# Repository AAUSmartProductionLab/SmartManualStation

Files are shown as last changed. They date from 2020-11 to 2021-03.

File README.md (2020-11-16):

 # Smart Manual Station overview
 The Smart Manual Station is a project developed at Aalborg University as a smart digital aid for the worker at a manual station. The station consists of:

  * Table on wheels 
  * Raspberry pi as the "brain"
  * Pick By Light setup
  * OPC-UA server
  * Simple GUI

further future features includes:
  * mqtt support
  * Storage database of pick by light setup
  * Implementation of RFID-scanner
  * Webinterface
  
 # The station itself

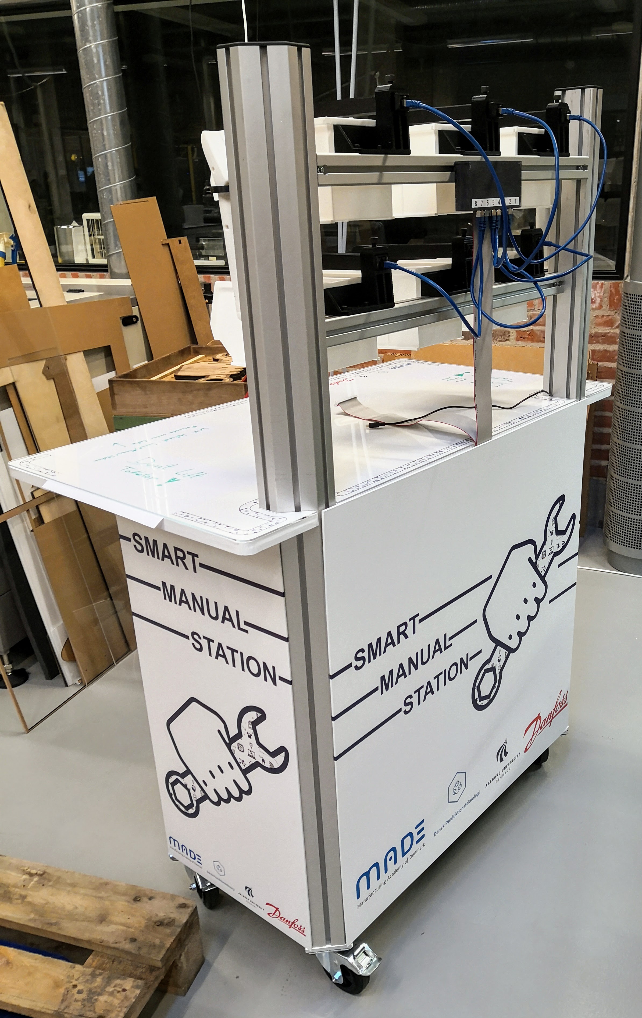
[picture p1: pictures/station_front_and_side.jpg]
  
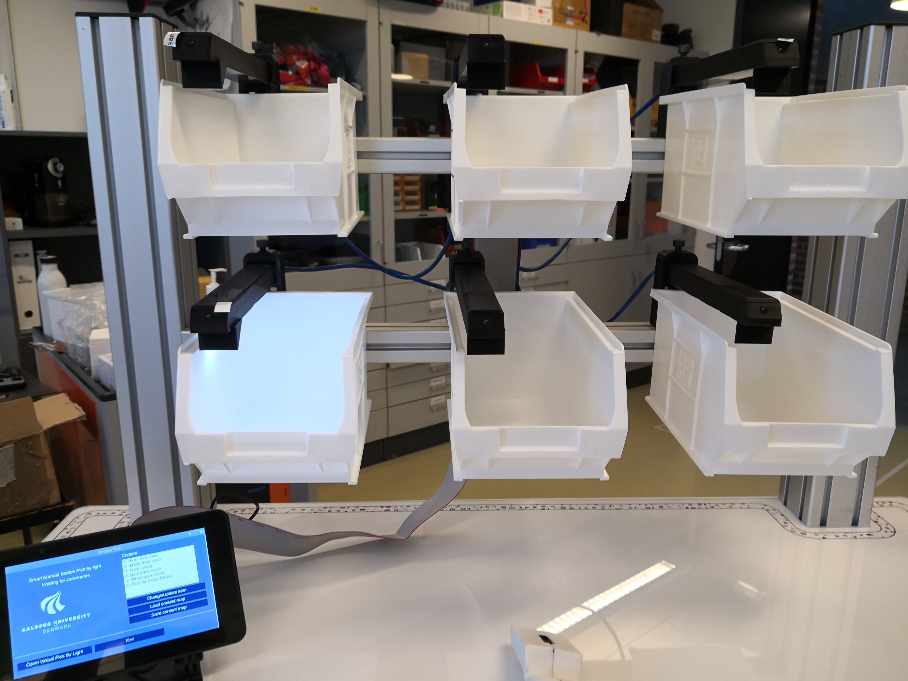
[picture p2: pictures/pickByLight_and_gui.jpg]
  

 # Graphical Unser Interface 
The graphical userinterface is build with [PySimpleGui](https://pysimplegui.readthedocs.io/en/latest/)  
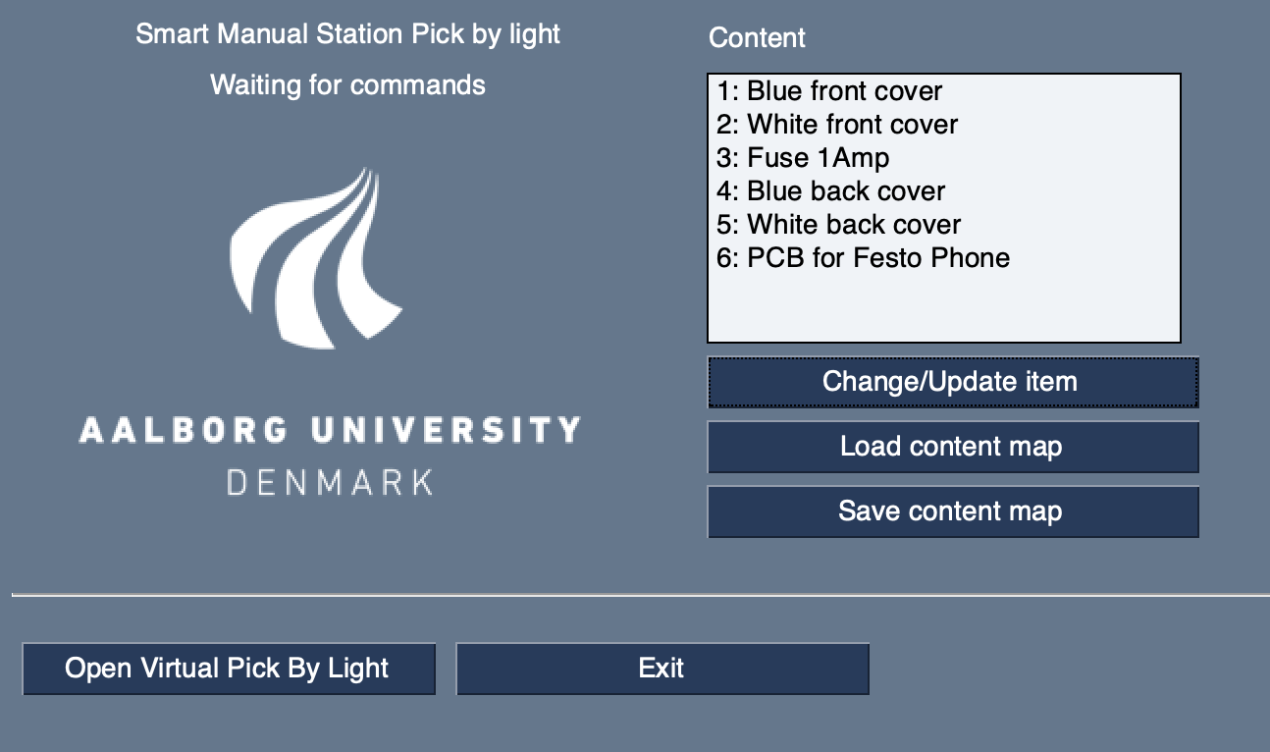
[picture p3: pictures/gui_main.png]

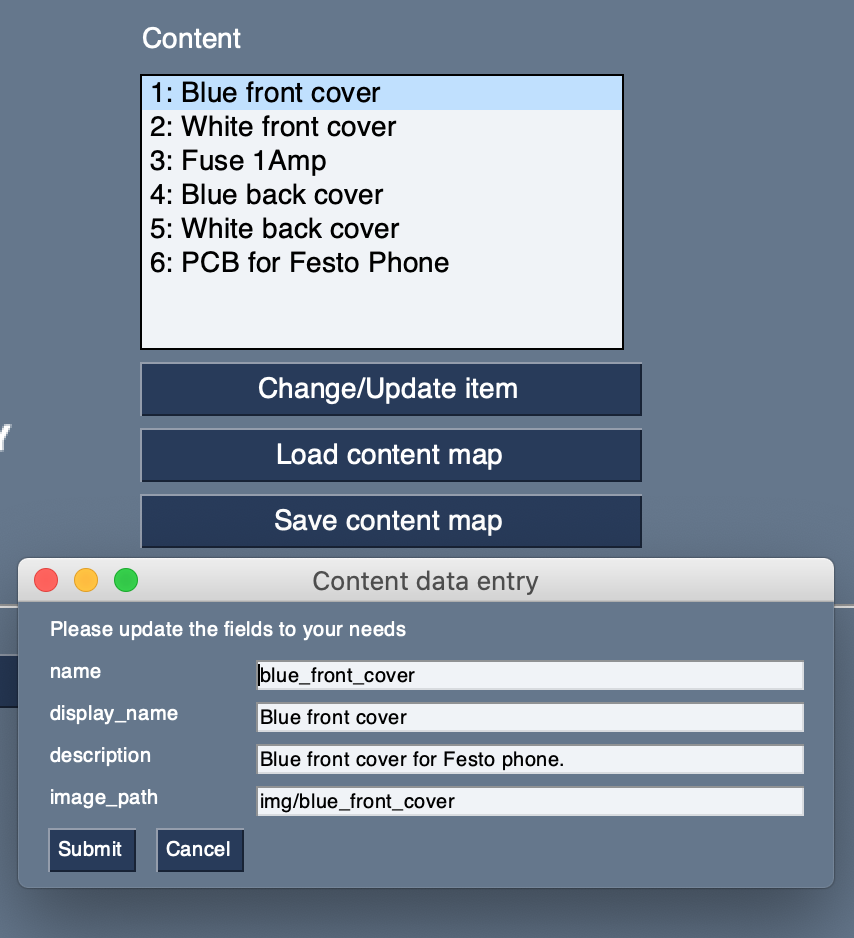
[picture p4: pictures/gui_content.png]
  

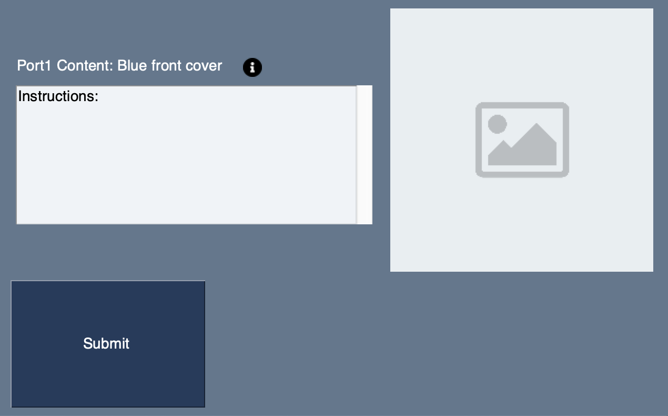
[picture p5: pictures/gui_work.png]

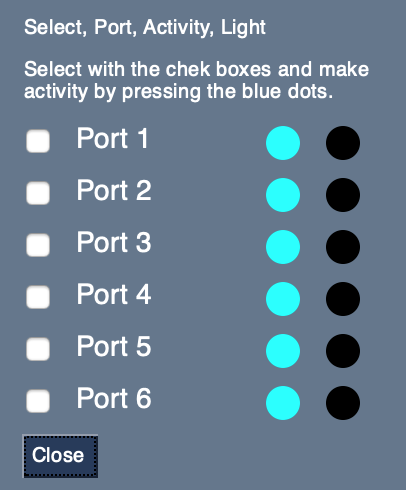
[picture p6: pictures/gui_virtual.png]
  

 # PCB breakout box
Added as a git subtree to this repository. Dedicated upstream repo can be found [here](https://github.com/hjalte33/rpi-pcb)  

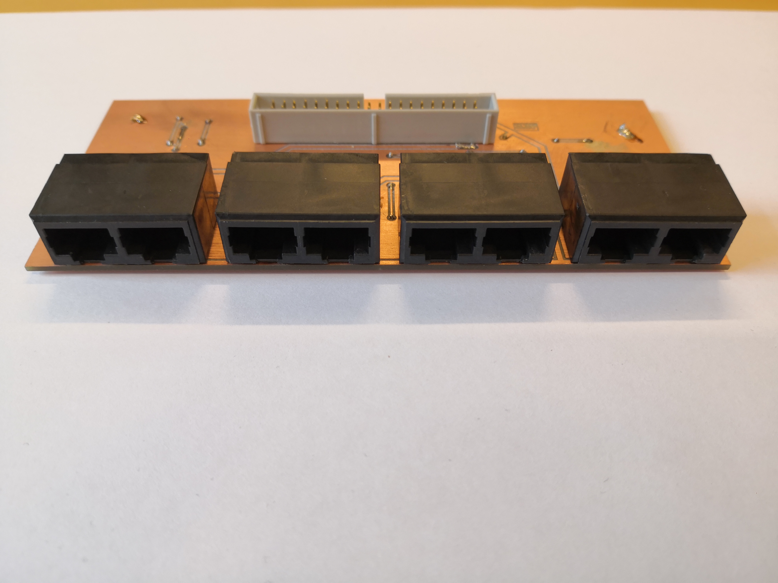
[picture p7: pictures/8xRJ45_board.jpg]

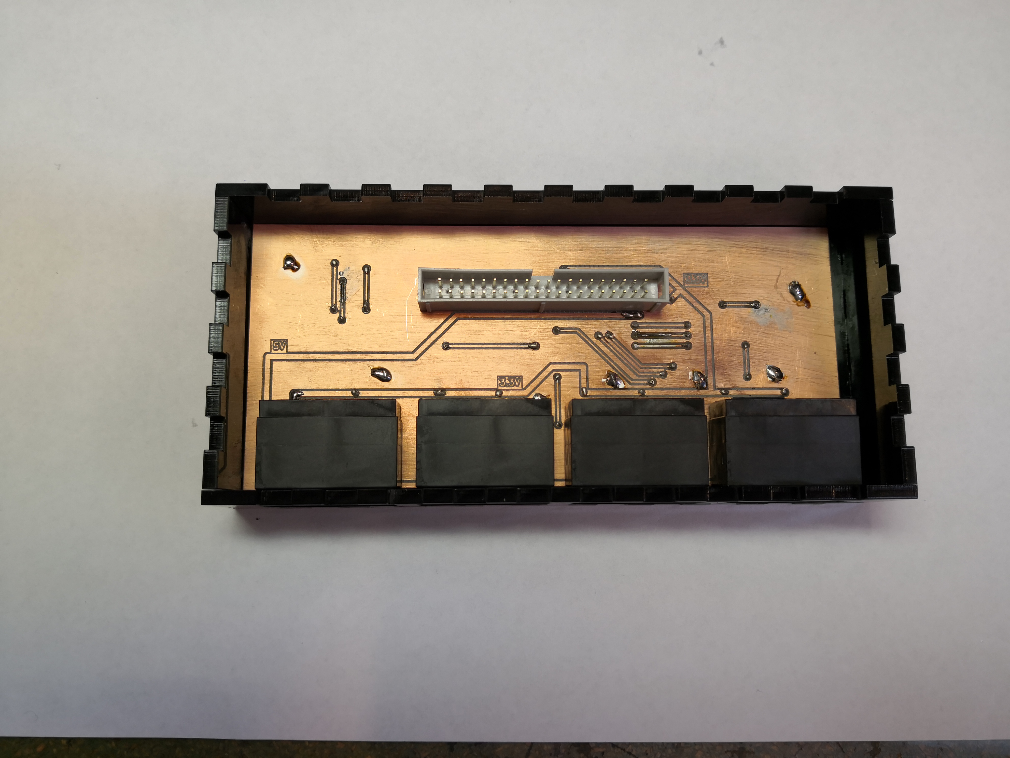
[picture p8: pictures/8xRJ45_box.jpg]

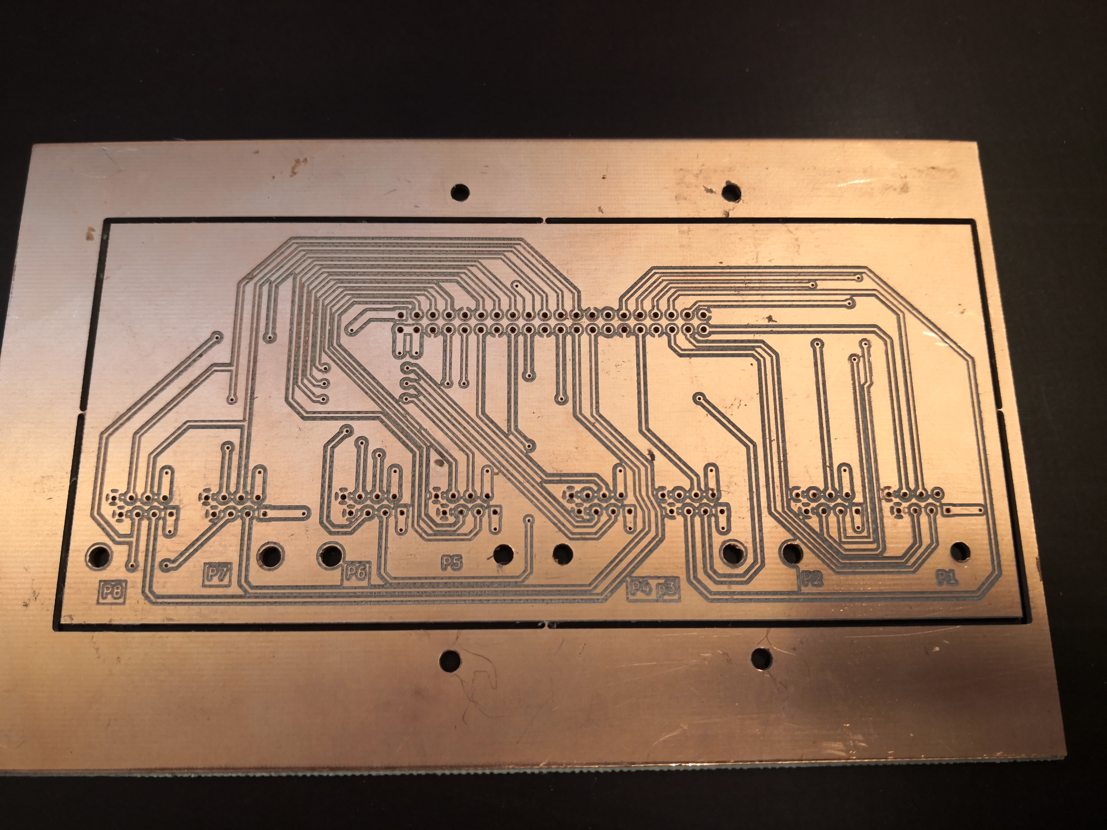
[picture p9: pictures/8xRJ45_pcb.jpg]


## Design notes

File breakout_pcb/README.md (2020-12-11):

# rpi-pcb is a Breakout board for raspberry pi.
With this breakout board you get eight rj45 ports with both 5v and 3.3v and three GPIOs in each port (exept port 8).
The various features of the the pins have been distributed nicely in a way that I think makes sense so for instance: 
 * Hardware SPI pins are all an port 1
 * Hardware I2C pins on port 5
 * Port 2, 3 and 4 each have a hardware pwm and gpclk pin
 * Port 6 have the UART tx and rx pins 
 * Port 7 and 8 have a shared SPI interface each with their own chip select pin.

See The full pinout [in the included pdf documentation](8xRJ45%20breakout%20board%20for%20raspberry%20pi%20-%20pinout.pdf)

    

## Box  
The repository also includes a nice lasercut box that fits snugly around the pcb.  


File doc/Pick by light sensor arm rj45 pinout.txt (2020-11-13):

1:5V
2:3.3V
3:PIR
4:LED
5:NC
6:NC
7:gnd
8:gnd

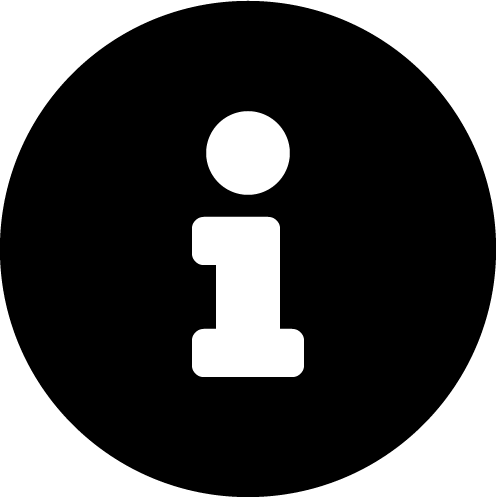
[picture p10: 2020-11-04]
src/img/info-circle-solid.png

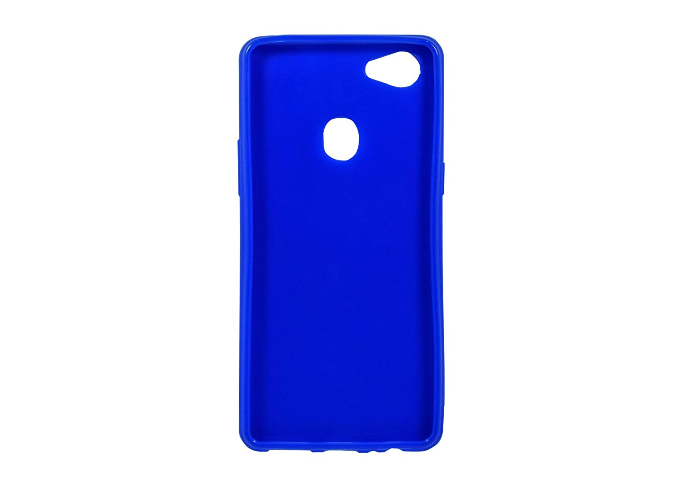
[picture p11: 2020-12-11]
src/img/blue_front_cover.jpg

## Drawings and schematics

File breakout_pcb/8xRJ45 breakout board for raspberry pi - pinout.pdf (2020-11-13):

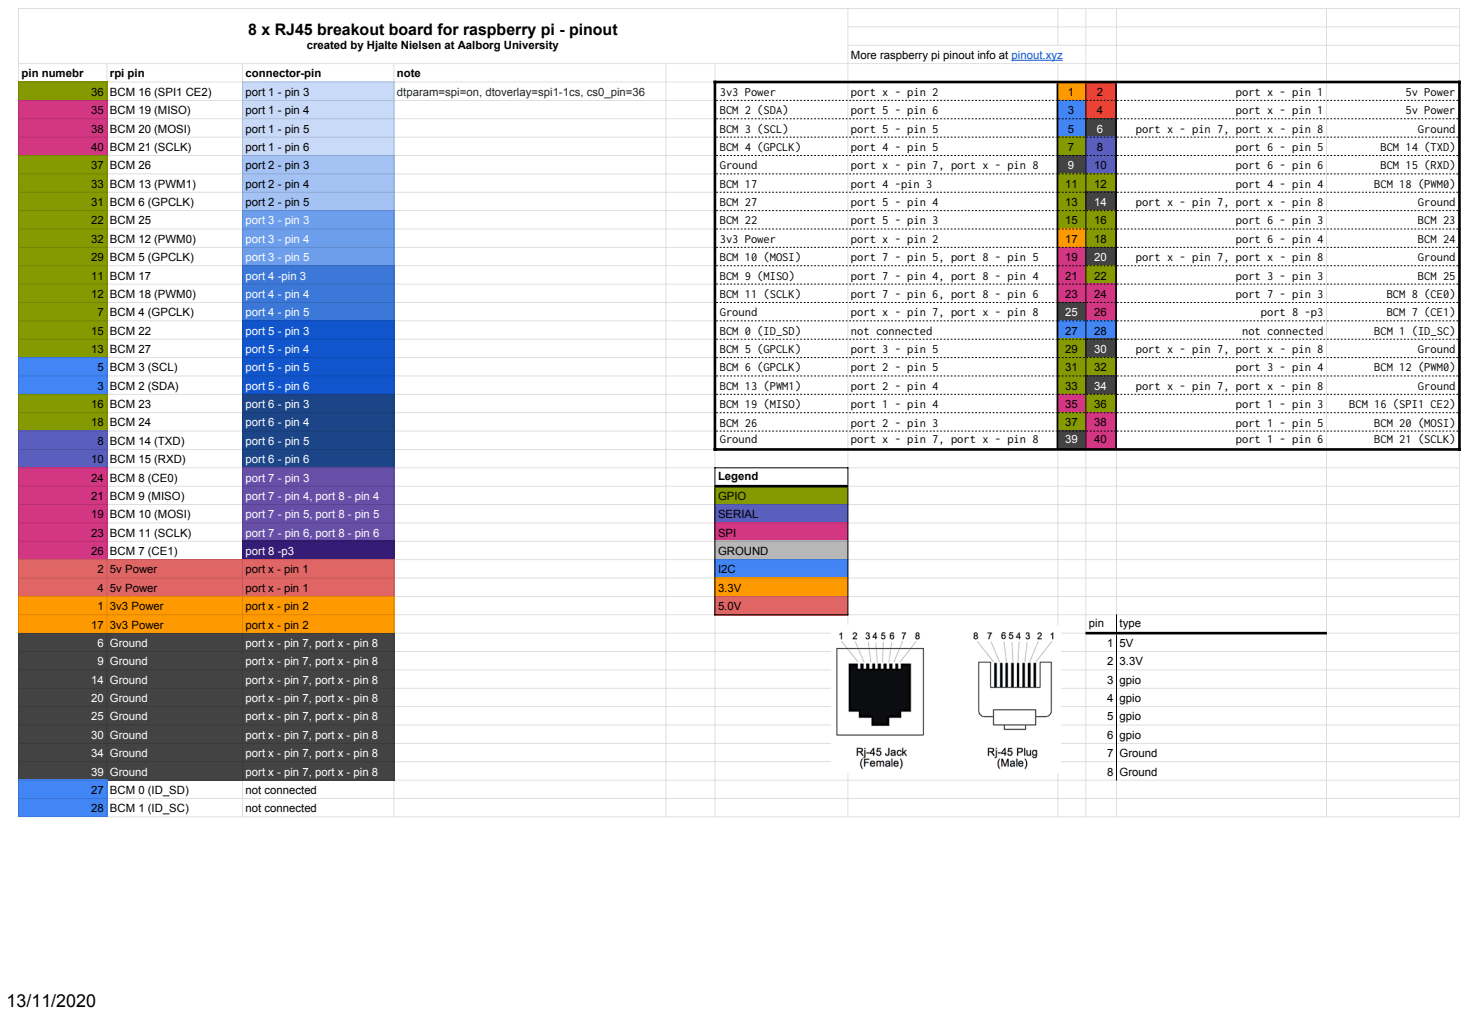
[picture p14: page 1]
created by Hjalte Nielsen at Aalborg University; More raspberry pi pinout info at pinout.xyz; pin numebr; rpi pin; connector-pin; note; 36 BCM 16 (SPI1 CE2); port 1 - pin 3; dtparam=spi=on, dtoverlay=spi1-1cs, cs0_pin=36; 3v3 Power; port x - pin 2; port x - pin 1; 5v Power; 35 BCM 19 (MISO); port 1 - pin 4; BCM 2 (SDA); port 5 - pin 6; 38 BCM 20 (MOSI); port 1 - pin 5; BCM 3 (SCL); port 5 - pin 5; port x - pin 7, port x - pin 8; Ground; 40 BCM 21 (SCLK); port 1 - pin 6; BCM 4 (GPCLK)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

8 x RJ45 breakout board for raspberry pi - pinout

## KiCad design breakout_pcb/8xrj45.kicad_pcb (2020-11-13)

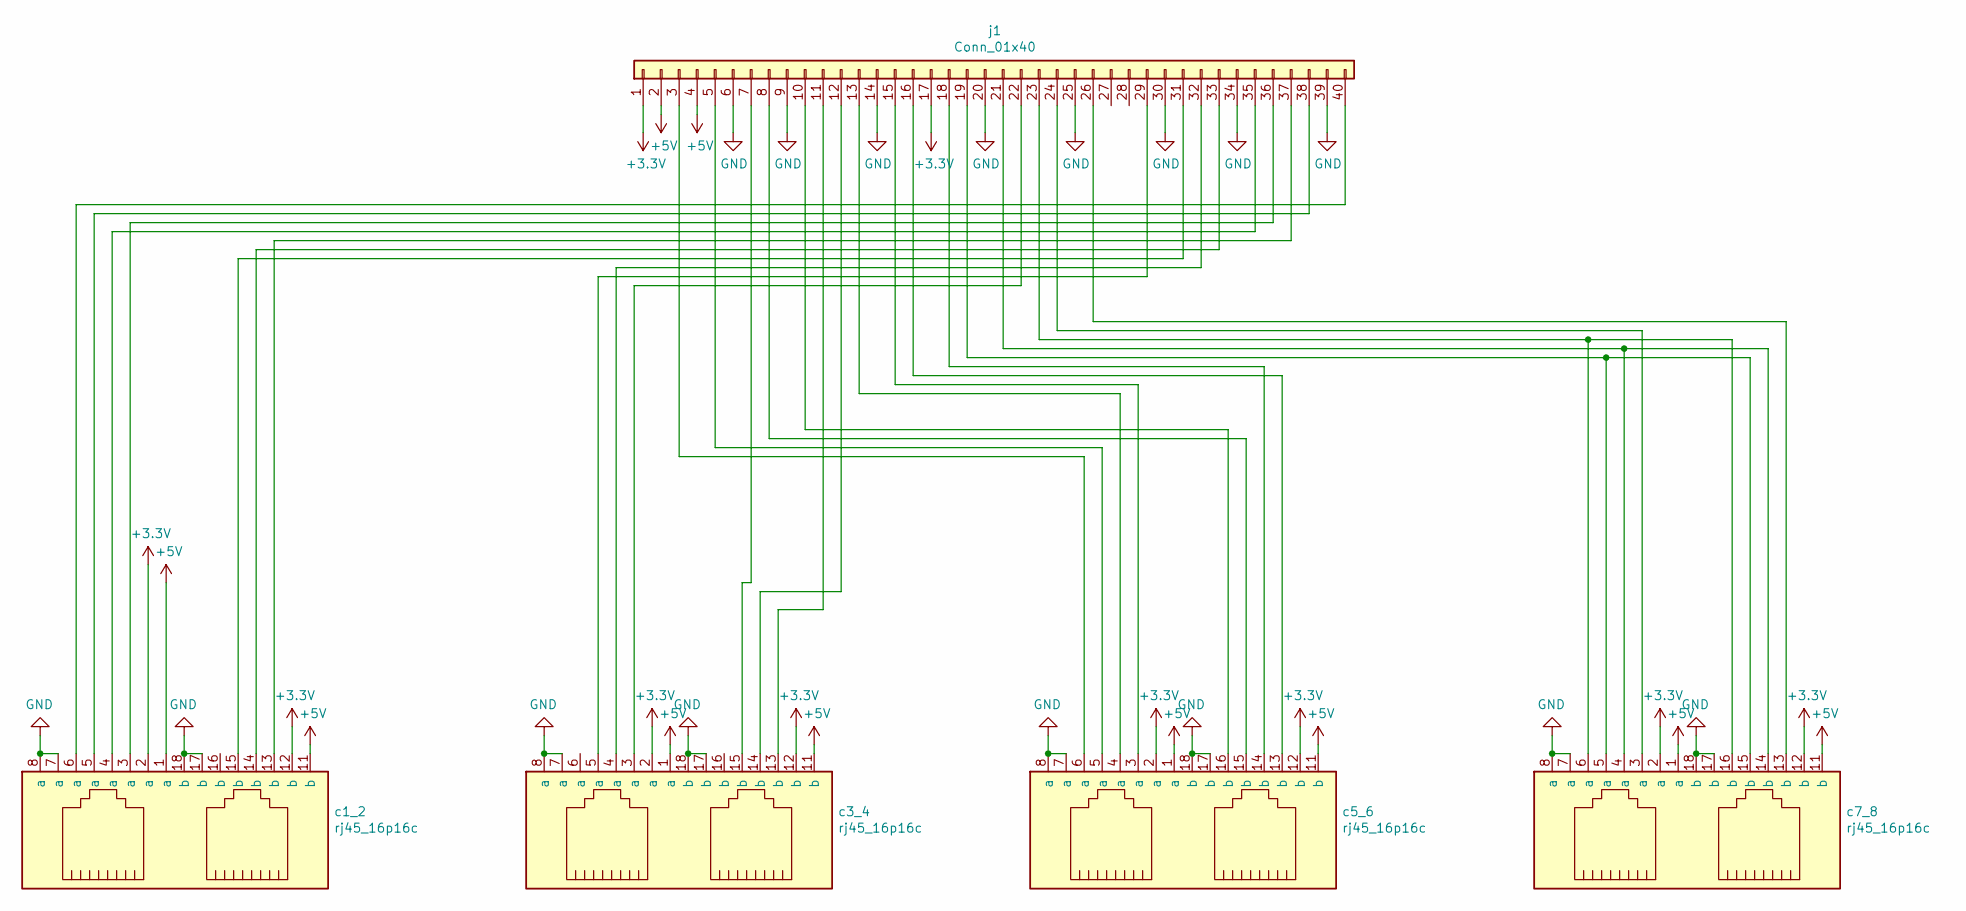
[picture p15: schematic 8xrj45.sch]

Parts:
c1_2, c3_4, c5_6, c7_8: rj45_16p16c; 2xrj45_connector
j1: Conn_01x40; IDC-Header_2x20_P2.54mm_Vertical

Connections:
+3V3: c1_2.2 (a), c1_2.12 (b), c3_4.2 (a), c3_4.12 (b), c5_6.2 (a), c5_6.12 (b), c7_8.2 (a), c7_8.12 (b), j1.1, j1.17
+5V: c1_2.1 (a), c1_2.11 (b), c3_4.1 (a), c3_4.11 (b), c5_6.1 (a), c5_6.11 (b), c7_8.1 (a), c7_8.11 (b), j1.2, j1.4
GND: c1_2.7 (a), c1_2.8 (a), c1_2.17 (b), c1_2.18 (b), c3_4.7 (a), c3_4.8 (a), c3_4.17 (b), c3_4.18 (b), c5_6.7 (a), c5_6.8 (a), c5_6.17 (b), c5_6.18 (b), c7_8.7 (a), c7_8.8 (a), c7_8.17 (b), c7_8.18 (b), j1.6, j1.9, j1.14, j1.20, j1.25, j1.30, j1.34, j1.39
unnamed: c1_2.3 (a), j1.36
unnamed: c1_2.4 (a), j1.35
unnamed: c1_2.5 (a), j1.38
unnamed: c1_2.6 (a), j1.40
unnamed: c1_2.13 (b), j1.37
unnamed: c1_2.14 (b), j1.33
unnamed: c1_2.15 (b), j1.31
unnamed: c3_4.3 (a), j1.22
unnamed: c3_4.4 (a), j1.32
unnamed: c3_4.5 (a), j1.29
unnamed: c3_4.13 (b), j1.11
unnamed: c3_4.14 (b), j1.12
unnamed: c3_4.15 (b), j1.7
unnamed: c5_6.3 (a), j1.15
unnamed: c5_6.4 (a), j1.13
unnamed: c5_6.5 (a), j1.5
unnamed: c5_6.6 (a), j1.3
unnamed: c5_6.13 (b), j1.16
unnamed: c5_6.14 (b), j1.18
unnamed: c5_6.15 (b), j1.8
unnamed: c5_6.16 (b), j1.10
unnamed: c7_8.3 (a), j1.24
unnamed: c7_8.13 (b), j1.26
unnamed: c7_8.4 (a), c7_8.14 (b), j1.21
unnamed: c7_8.5 (a), c7_8.15 (b), j1.19
unnamed: c7_8.6 (a), c7_8.16 (b), j1.23

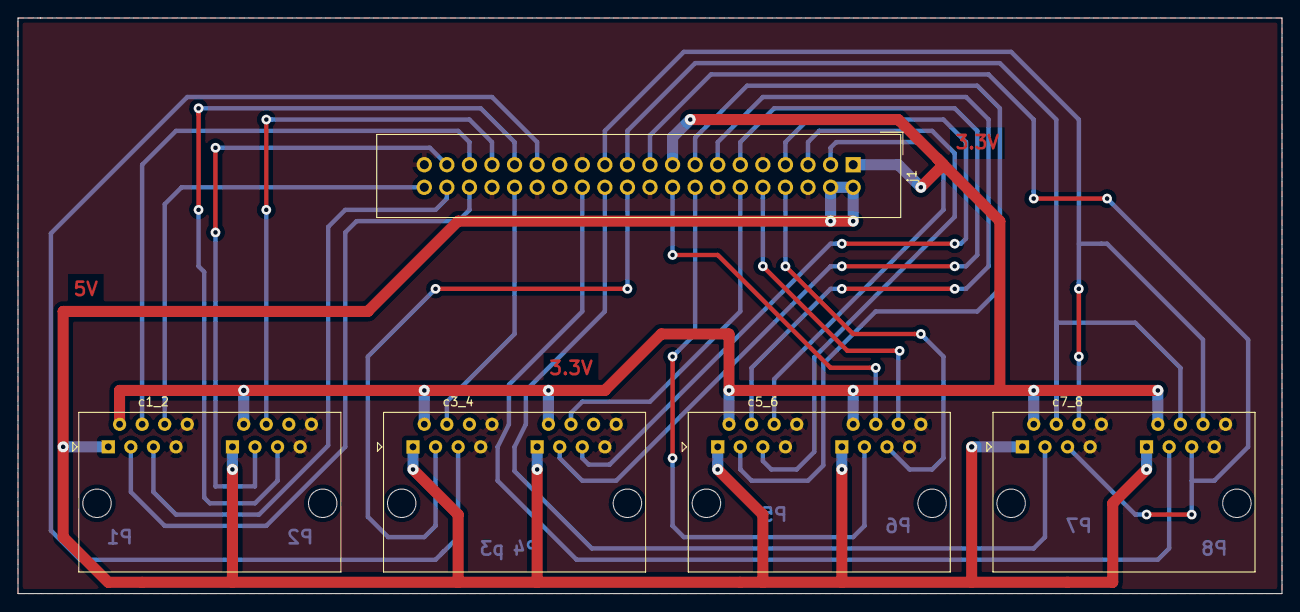
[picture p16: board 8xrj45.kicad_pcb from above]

Board: 2 copper layers, 142.2 x 64.8 mm, 5 parts (0 on the bottom side), 29 nets.

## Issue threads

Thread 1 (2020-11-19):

Another LED option

PySimpleGUI, 2020-11-19:
I discovered another option for making LED indicators in GUIs that only use Text elements that you might be interested in.  It's a little less complicated than drawing on Graph elements.  You'll find a demo here that shows the technique:

https://github.com/PySimpleGUI/PySimpleGUI/blob/master/DemoPrograms/Demo_LED_Indicators_Text_Based.py

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

hjalte33, 2020-11-21:
Nice and thanks.
This is definitely a simple method. It will take a little rework to make it do the color changing and fading effects that i use but looks doable.

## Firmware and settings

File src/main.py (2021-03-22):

#!/usr/bin/python3

import argparse
import pick_by_light
import gui
import station_ua_server as suas
import station_festo_connect as festo_connect
import coloredlogs, logging  
import os

coloredlogs.install(level = logging.WARNING)
logger = logging.getLogger(__name__)

# Allow for arguments being passed to this file 
parser = argparse.ArgumentParser(
    description='Smart Manual Station Project at Aalborg University'
)
parser.add_argument("-v", "--verbose", help="increase output verbosity", action="store_true")
parser.add_argument("-d", "--dummy", help="run in dummy mode without the actual hardware", action="store_true")
parser.add_argument("-C", "--content_map", help="path to the content map", type=str)
parser.add_argument("-f", "--festo_connect", help="enable festo connect", action="store_true")
parser.add_argument("-i", "--festo_connect_ip", help="ip address for festo connect", type=str)

# If verbose flag set the debugger level accordingly on all improted files 
# TODO Setting the debug level seems to not work correctly.
args = parser.parse_args()
if args.verbose:
    logger.setLevel(logging.DEBUG)
    pick_by_light.logger.setLevel(logging.DEBUG)
    suas.logger.setLevel(logging.WARNING)
    gui.logger.setLevel(logging.DEBUG)

# Load either the dummy ports or the pi ports depending on passed argument
if args.dummy:
    from dummy_port import DummyPort as Port
    logger.warning("Running in dummy mode")
else:
    from pi_port import PiPort as Port
    # load the default ports
    Port.load_pinout_from_file(pin_conf_name = 'default_pin_config.yaml')

# If a path string for a content map has been passed, save it, else set default.
if args.content_map:
    content_map = args.content_map
else:
    content_map = 'content_map.yaml'


if __name__ == "__main__":
    # generate 6 ports 
    ports = [Port(i) for i in range(1,7)]

    # Create our pick by light object
    PBL = pick_by_light.PickByLight(ports, default_content_map_path=content_map)

    # Create our station ua serer, passing in our pick by light instance.
    SUAS = suas.StationUAServer(PBL)

    # Create our gui interface, passing in our pick by light instance.
    GUI = gui.Gui(PBL)

    if args.festo_connect:
        # Create festo connect object
        FC = festo_connect.FestoServer(PBL,args.festo_connect_ip)

    try:
        # GUI.run blocks untill it exits
        GUI.run()
    except KeyboardInterrupt:
        print('interrupted!')
    finally:
        # Finally stop the ua server
        SUAS.ua_server.stop()

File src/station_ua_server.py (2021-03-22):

from opcua import ua, Server, Node
from time import sleep
from threading import Thread, Event
from datetime import datetime

import logging  
logger = logging.getLogger(__name__)
logger.setLevel(logging.WARNING)

class StationUAServer:
    def __init__(self,pick_by_light):
        self._pbl = pick_by_light
        self._setup_nodes()
        self._generate_tags()

        self.ua_server.start()
        
        self._generate_subscriptions()
        Thread(target=self._var_updater, daemon=True).start()

    def _setup_nodes(self):        
        
        # Create server instance 
        self.ua_server = Server('./opcua_cache')
        self.ua_server.set_endpoint('opc.tcp://0.0.0.0:4840/UA/PickByLight')
        self.ua_server.set_server_name("Pick By Light Server")
        # idx name will be used later for creating the xml used in data type dictionary
        # setup our own namespace, not really necessary but should as spec
        idx_name = 'http://examples.freeopcua.github.io'
        self.idx = self.ua_server.register_namespace(idx_name)
        
        # Set all possible endpoint policies for clients to connect through
        self.ua_server.set_security_policy([
            ua.SecurityPolicyType.NoSecurity,
            ua.SecurityPolicyType.Basic128Rsa15_SignAndEncrypt,
            ua.SecurityPolicyType.Basic128Rsa15_Sign,
            ua.SecurityPolicyType.Basic256_SignAndEncrypt,
            ua.SecurityPolicyType.Basic256_Sign])

        # get Objects node, this is where we should put our custom stuff
        objects = self.ua_server.get_objects_node()

        # Create objects for the pack tags using the above created packMLBasedObjectType
        self.Status = objects.add_folder('ns=2;s=Status', "Status")
        self.Command = objects.add_folder('ns=2;s=Command', "Command")
        self.Command.add_method('ns=2;s=Command.SelectPort', "SelectPort", self._select_method, [ua.VariantType.Int32, ua.VariantType.String], [ua.VariantType.Boolean])
        self.Command.add_method('ns=2;s=Command.DeselectPort', "DeselectPort", self._deselect_method, [ua.VariantType.Int32], [ua.VariantType.Boolean])
        self.Command.add_method('ns=2;s=Command.DeselectAllPorts', "DeselectAllPorts", self._deselect_all_method, [], [ua.VariantType.Boolean])


        root = self.ua_server.get_root_node()
        DummyFestoObj = root.add_object("ns=2;s=|var|CECC-LK.Application.Flexstation_globalVariables", "DummyFesto")
        DummyFestoObj.add_variable("ns=2;s=|var|CECC-LK.Application.Flexstation_globalVariables.FlexStationStatus", "FlexStationStatus", val=0).set_writable()
        DummyFestoObj.add_variable("ns=2;s=|var|CECC-LK.Application.FBs.stpStopper1.stAppControl.uiOpNo","uiOpNo", val=0).set_writable()
        DummyFestoObj.add_variable("ns=2;s=ns=2;s=|var|CECC-LK.Application.AppModul.stRcvData.sOderDes","sOderDes", val="").set_writable()
        

    def _generate_tags(self):
        # for all ports generate tags
        for port_number, port in self._pbl.get_ports():
            # Make a folder with the port_number as the name
            b_obj = self.Status.add_object('ns=2;s=Status.Port_{}'.format(port_number), "Port_{}".format(port_number))
            
            content = self._pbl.get_content(port_number)

            b_obj.add_variable("ns=2;s=Status.Port_{}.Selected".format(port_number)             ,"Selected"            , bool())
            b_obj.add_variable("ns=2;s=Status.Port_{}.WorkFinished".format(port_number)         ,"WorkFinished"        , bool())
            b_obj.add_variable("ns=2;s=Status.Port_{}.Instructions".format(port_number)         ,"Instructions"        , "")
            b_obj.add_variable("ns=2;s=Status.Port_{}.Activity".format(port_number)             ,"Activity"            , bool())
            b_obj.add_variable("ns=2;s=Status.Port_{}.ActivityTimestamp".format(port_number)    ,"ActivityTimestamp"   , datetime.fromtimestamp(0))
            b_obj.add_variable("ns=2;s=Status.Port_{}.LightState".format(port_number)           ,"LightState"          , 0)
            b_obj.add_variable("ns=2;s=Status.Port_{}.ContentDisplayName".format(port_number)   ,"ContentDisplayName"  , content['display_name'])
            b_obj.add_variable("ns=2;s=Status.Port_{}.ContentName".format(port_number)          ,"ContentName"         , content['name'])
            b_obj.add_variable("ns=2;s=Status.Port_{}.ContentDescription".format(port_number)   ,"ContentDescription"  , content['description'])
            b_obj.add_variable("ns=2;s=Status.Port_{}.ContentImagePath".format(port_number)     ,"ContentImagePath"    , content['image_path'])

            '''
            create command tags for clients that does not support ua methods. 
            '''
            b_obj = self.Command.add_object('ns=2;s=Command.Port_{}'.format(port_number), "Port_{}".format(port_number))

            b_obj.add_variable("ns=2;s=Command.Port_{}.Select".format(port_number)               ,"Select"              , bool()).set_writable()
            b_obj.add_variable("ns=2;s=Command.Port_{}.Deselect".format(port_number)             ,"Deselect"            , bool()).set_writable()
            b_obj.add_variable("ns=2;s=Command.Port_{}.Instructions".format(port_number)         ,"Instructions"        , "").set_writable()
            b_obj.add_variable("ns=2;s=Command.Port_{}.ContentDisplayName".format(port_number)   ,"ContentDisplayName"  , content['display_name']).set_writable()
            b_obj.add_variable("ns=2;s=Command.Port_{}.ContentName".format(port_number)          ,"ContentName"         , content['name']).set_writable()
            b_obj.add_variable("ns=2;s=Command.Port_{}.ContentDescription".format(port_number)   ,"ContentDescription"  , content['description']).set_writable()
            b_obj.add_variable("ns=2;s=Command.Port_{}.ContentImagePath".format(port_number)     ,"ContentImagePath"    , content['image_path']).set_writable()
        
        '''
        Generate some common commands 
        '''
        # Make a folder for the commons
        b_obj = self.Command.add_object('ns=2;s=Command.ByContent', 'ByContent')

        b_obj.add_variable("ns=2;s=Command.ByContent.Select"         ,"Select"          , bool()).set_writable()
        b_obj.add_variable("ns=2;s=Command.ByContent.Deselect"       ,"Deselect"        , bool()).set_writable()
        b_obj.add_variable("ns=2;s=Command.ByContent.Name"           ,"Name"            , ""    ).set_writable()
        b_obj.add_variable("ns=2;s=Command.ByContent.Instructions"   ,"Instructions"    , ""    ).set_writable()
        b_obj.add_variable("ns=2;s=Command.ByContent.Result"         ,"Result"          , -1    ).set_writable()
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

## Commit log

2020-09-09 v2 design
    [8xrj45-B_Cu.gbr, 8xrj45-B_Mask.gbr, 8xrj45-B_Paste.gbr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]
2020-09-21 fresh export
    [8xrj45.kicad_pcb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]
2020-10-13 Logging and working OPCUA server + minor fixes
    [dummy_port.py, main.py, pi_port.py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]
2020-11-03 disabled dummy pick thread
2020-11-11 fix major racecondition bug blocking writes
    [station_ua_server.py]
2020-11-11 cleanup and small bug fixes.
    [main.py, pick_by_light.py]
2020-11-13 move aux origin
    [8xrj45.kicad_pcb]
2020-11-13 fix: pin 5 and 6 are not connected
2020-11-13 documentation and cad
2020-11-13 add: lasercut files
2020-11-23 bugfix: path not file when loading images
    [gui.py]
2021-02-16 Festo connect fix (#3)
    * compleatly rewritten for new pic by light api
    * add work_finished tag to port state
    * use work_finished() on pbl when submitting work.
    * add: festo connect
    * bugfixes
    * add dummy festo object: orderDescription
    [gui.py, main.py, pick_by_light.py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]
